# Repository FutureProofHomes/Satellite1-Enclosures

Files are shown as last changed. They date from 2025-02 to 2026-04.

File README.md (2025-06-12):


<!--
*** Readme based upon Best-README-Template.
-->

<!-- PROJECT SHIELDS -->
<!--
*** I'm using markdown "reference style" links for readability.
*** Reference links are enclosed in brackets [ ] instead of parentheses ( ).
*** See the bottom of this document for the declaration of the reference variables
*** for contributors-url, forks-url, etc. This is an optional, concise syntax you may use.
*** https://www.markdownguide.org/basic-syntax/#reference-style-links
-->
[][contributors-url]
[][forks-url]
[][stars-url]
[][issues-url]
[][license-url]
[][linkedin-url]

<!-- PROJECT LOGO -->
<br />
<div align="center">
  <a href="https://github.com/FutureProofHomes/Satellite1-Enclosures">
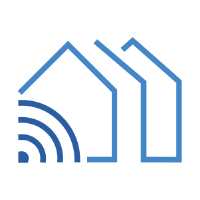
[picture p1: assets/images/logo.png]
    
  </a>

<h3 align="center">Satellite1 Voice Assistant Enclosures</h3>

  <p align="center">
    3D printable geometry and project files for enclosures relating to the Satellite1 AI-Powered Voice Assistant and its accessories.
    <br />
    <a href="https://docs.futureproofhomes.net"><strong>Explore the docs »</strong></a>
    <br />
    <br />
    <a href="https://www.youtube.com/@futureproofhomes">View Demos</a>
    ·
    <a href="https://github.com/FutureProofHomes/Satellite1-Enclosures/issues/new?labels=bug&template=bug-report---.md">Report Bug</a>
    ·
    <a href="https://github.com/FutureProofHomes/Satellite1-Enclosures/issues/new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">Request Feature</a>
  </p>
</div>

<!-- TABLE OF CONTENTS -->
<details>
  <summary>Table of Contents</summary>
  <ol>
    <li>
      <a href="#about-the-project">About The Project</a>
    </li>
    <li>
      <a href="#getting-started">Getting Started</a>
    </li>
    <li><a href="#contributing">Contributing</a></li>
    <li><a href="#license">License</a></li>
    <li><a href="#contact">Contact</a></li>
    <li><a href="#acknowledgments">Acknowledgments</a></li>
  </ol>
</details>

<!-- ABOUT THE PROJECT -->
## About the Project
The enclosures in this repo relate to the Satellite1 Voice Assistant

<div style="text-align: center;">
    <a href="https://docs.futureproofhomes.net/satellite1-squircle-enclosures">
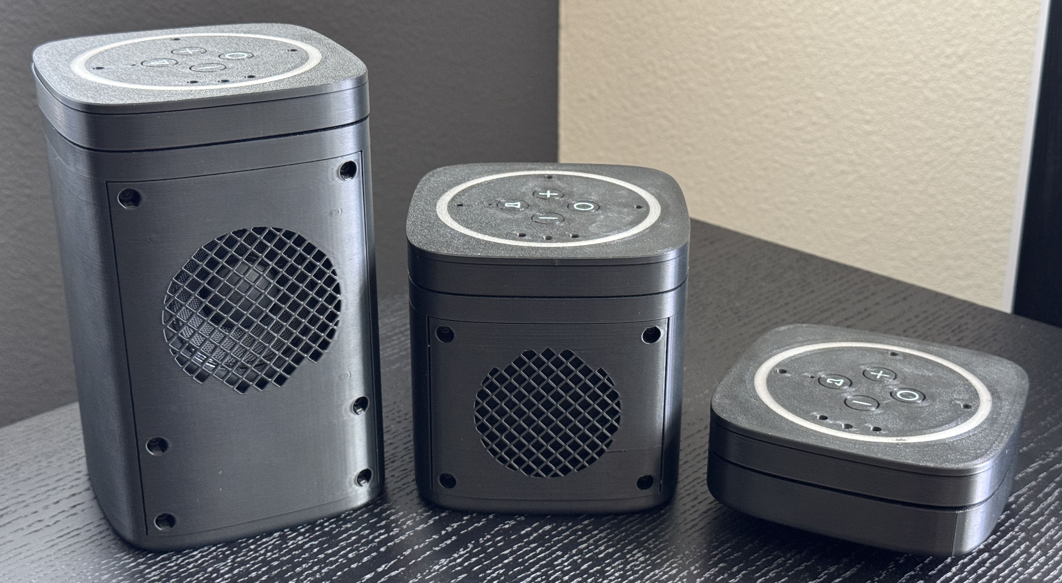
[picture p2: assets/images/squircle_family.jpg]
Sat1 Pose Tall
        
    </a>
</div>

<!-- GETTING STARTED -->
## Getting Started

Go to [Docs.FutureProofHomes.net/satellite1-squircle-enclosures](https://docs.futureproofhomes.net/satellite1-squircle-enclosures) and follow the instructions to print and assemble your enclosure.

<!-- CONTRIBUTING -->
## Contributing

Contributions are what make the open source community such an amazing place to learn, inspire, and create. Any contributions you make are **greatly appreciated**.

If you have a suggestion that would make this better, please fork the repo and create a pull request. You can also simply open an issue with the tag "enhancement".
Don't forget to give the project a star! Thanks again!

1. Fork the Project
3. Create your Feature Branch (`git checkout -b feature/AmazingFeature`)
4. Commit your Changes (`git commit -m 'Add some AmazingFeature'`)
5. Push to the Branch (`git push origin feature/AmazingFeature`)
6. Open a Pull Request

<p align="right">(<a href="#readme-top">back to top</a>)</p>

<!-- LICENSE -->
## License

Distributed under the CERN Open Hardware Licence Version 2 - Strongly Reciprocal Licesnse. See LICENSE.txt for more information.  See `LICENSE.txt` for more information.

<p align="right">(<a href="#readme-top">back to top</a>)</p>

<!-- CONTACT -->
## Contact

FutureProofHomes  - [Website](https://futureproofhomes.net/)

<p align="right">(<a href="#readme-top">back to top</a>)</p>

<!-- YouTube -->
## YouTube

Checkout out our growing YouTube Channel  - [YouTube.com/@FutureProofHomes](https://www.youtube.com/@futureproofhomes)

<p align="right">(<a href="#readme-top">back to top</a>)</p>

<!-- ACKNOWLEDGMENTS -->
## Acknowledgments

* @alextrical for the beautiful CAD work
* @j4ys0n for the early prototypes
* Your name here soon...

<p align="right">(<a href="#readme-top">back to top</a>)</p>

<!-- MARKDOWN LINKS & IMAGES -->
<!-- https://www.markdownguide.org/basic-syntax/#reference-style-links -->
[contributors-shield]: https://img.shields.io/github/contributors/FutureProofHomes/Satellite1-ESPHome.svg?style=for-the-badge
[contributors-url]: https://github.com/FutureProofHomes/Satellite1-Enclosures/graphs/contributors
[forks-shield]: https://img.shields.io/github/forks/FutureProofHomes/Satellite1-ESPHome.svg?style=for-the-badge
[forks-url]: https://github.com/FutureProofHomes/Satellite1-Enclosures/network/members
[stars-shield]: https://img.shields.io/github/stars/FutureProofHomes/Satellite1-ESPHome.svg?style=for-the-badge
[stars-url]: https://github.com/FutureProofHomes/Satellite1-Enclosures/stargazers
[issues-shield]: https://img.shields.io/github/issues/FutureProofHomes/Satellite1-ESPHome.svg?style=for-the-badge
[issues-url]: https://github.com/FutureProofHomes/Satellite1-Enclosures/issues
[license-shield]: https://img.shields.io/github/license/FutureProofHomes/Satellite1-ESPHome.svg?style=for-the-badge
[license-url]: https://github.com/FutureProofHomes/Satellite1-Enclosures/blob/master/LICENSE.txt
[linkedin-shield]: https://img.shields.io/badge/-LinkedIn-black.svg?style=for-the-badge&logo=linkedin&colorB=555
[linkedin-url]: https://linkedin.com/in/linkedin_username
[genaimockup]: assets/images/mockup.png
[combo_render]: assets/images/combo_render.png
[kicad.org]: https://img.shields.io/badge/KiCad-314CB0?style=for-the-badge&logo=kicad&logoColor=white
[kicad-url]: https://www.kicad.org/
[esphome.io]: https://img.shields.io/badge/-ESPHome-000000?style=for-the-badge&logo=esphome&logoColor=white
[esphome-url]: https://esphome.io/

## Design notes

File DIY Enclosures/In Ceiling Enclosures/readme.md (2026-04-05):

This is the minimalistic enclosure to place your Sat1.x DevKit into the ceiling<br>
<br>
it is designed to be powered through USB or with our PoE Shoe (est. availabilty end 2026)<br>
This enclosure isn't designed to host an speaker inside.<br>
<br>
You need following extra parts aside the DevKit itself:<br>
- <a href="https://aliexpress.com/item/1005010265420927.html">4x M3x12mm self tapping screws<br>
- <a href="https://aliexpress.com/item/1005010265420927.html">4x M3x4mm self tapping screws<br>
- <a href="https://aliexpress.com/item/1005009490995202.html">4x Downlight Spring Bracket<br>
<br>
For easy printing, use the provided Slicer Project files.<br>
the faceplate mesh is created with a height modifier inside the project.<br>
- use a height modifier from 0.00-2.00mm<br>
- set top and bottom layers to 0<br>
- set infill to 70%<br>
- set infill to tri-hexagon<br>
- set "only one wall on first layer"<br>
<br>
Be aware, your filament flow has to be dialed in.

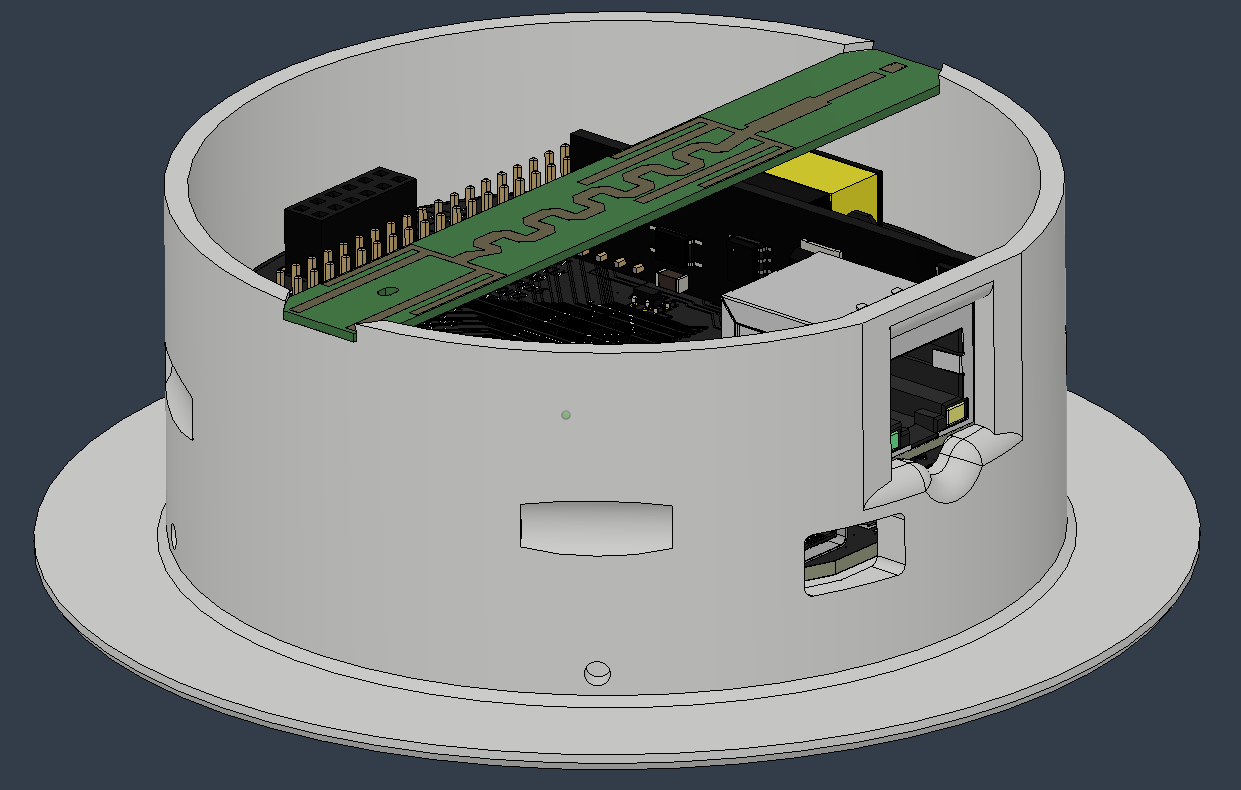
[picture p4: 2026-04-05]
DIY Enclosures/In Ceiling Enclosures/pictures/In Ceiling Mini.png

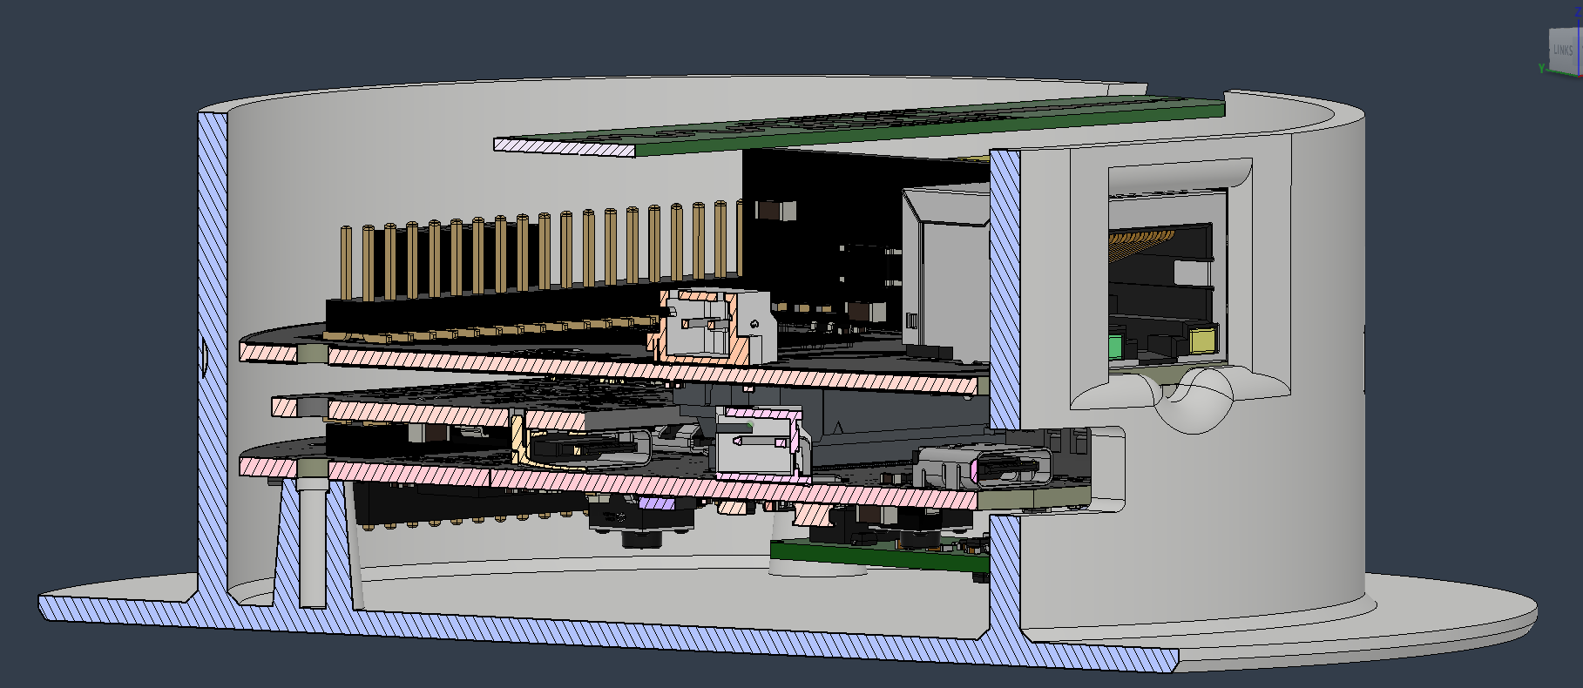
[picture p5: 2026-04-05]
DIY Enclosures/In Ceiling Enclosures/pictures/In Ceiling Mini cross cut view.png

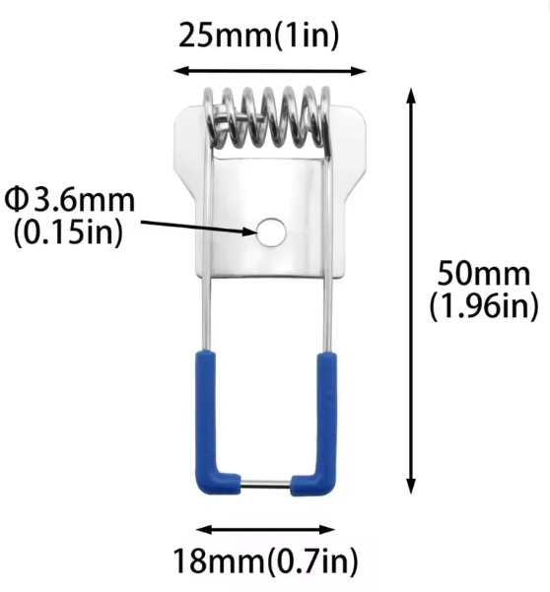
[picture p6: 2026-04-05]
DIY Enclosures/In Ceiling Enclosures/pictures/Spring brackets.png

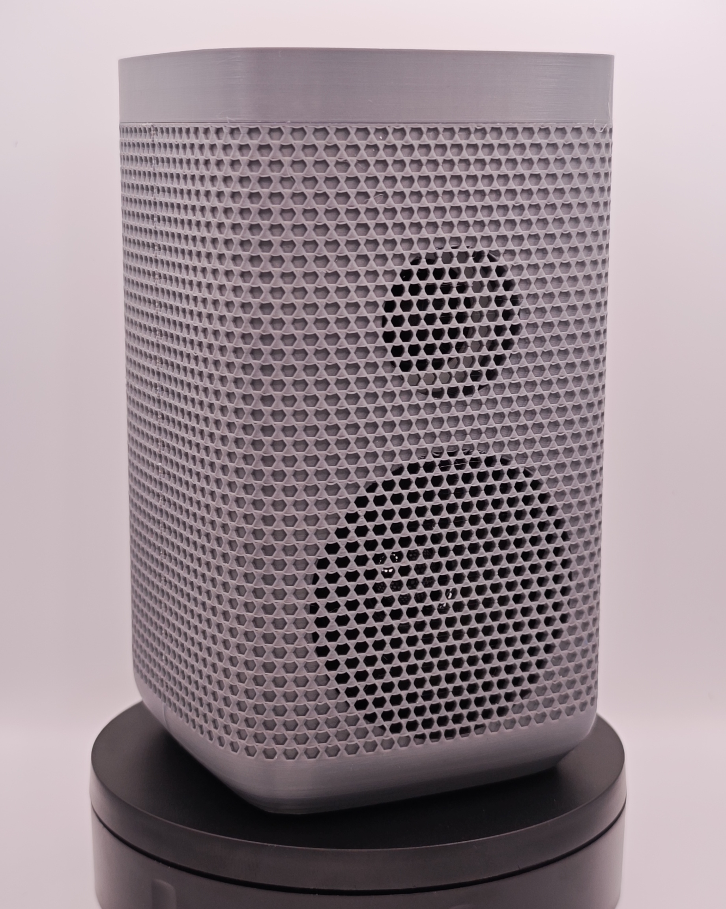
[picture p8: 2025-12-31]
assets/images/sat1_enclosure_kit.jpg

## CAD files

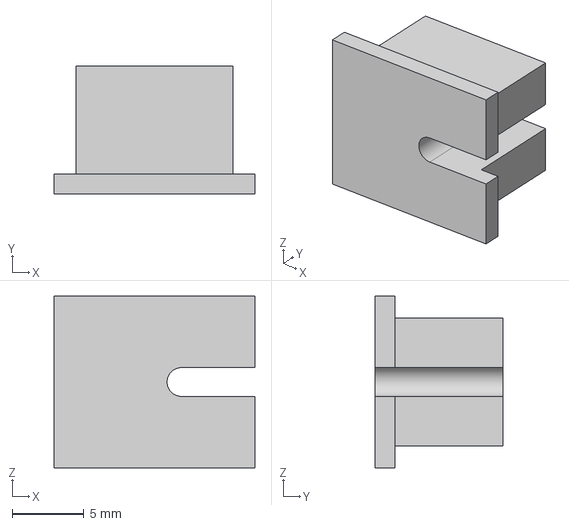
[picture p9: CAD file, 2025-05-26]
DIY Enclosures/Cylindrical Enclosures/Geometry Files/STEP/General Parts/2mm Wire Cover.step
14.0 x 8.90 x 11.9 mm

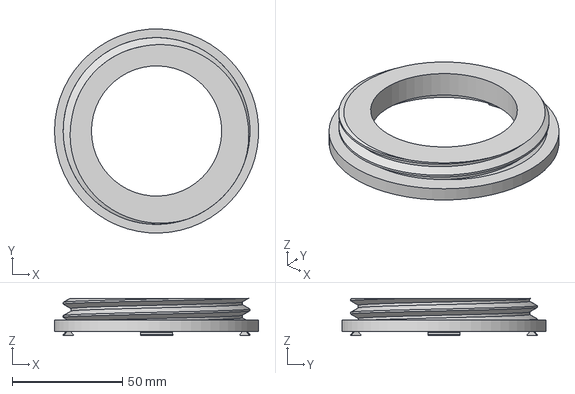
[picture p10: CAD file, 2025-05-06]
DIY Enclosures/Cylindrical Enclosures/Geometry Files/STEP/Speaker - Dayton Audio RS75-4/Speaker Adapter - RS75-4.step
92.4 x 92.5 x 16.9 mm

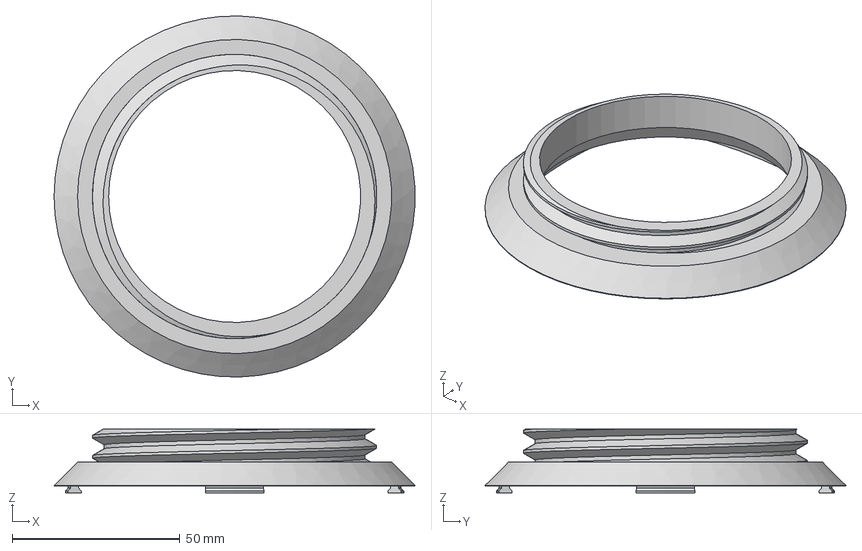
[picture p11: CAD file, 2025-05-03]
DIY Enclosures/Cylindrical Enclosures/Geometry Files/STEP/Speaker - GRS 3FR-4/Speaker Adapter - GRS 3FR-4.step
107.4 x 107.5 x 18.9 mm

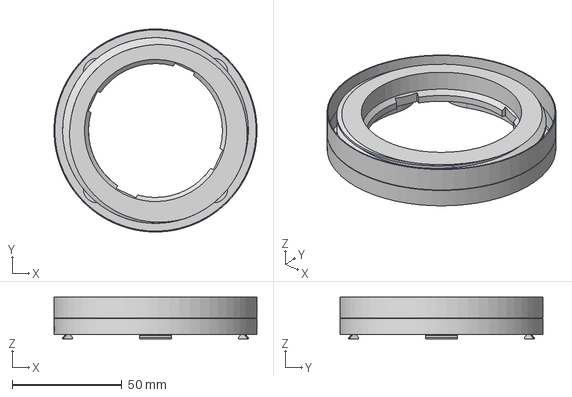
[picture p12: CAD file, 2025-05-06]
DIY Enclosures/Cylindrical Enclosures/Geometry Files/STEP/Speaker - TEBM46C - 20N/Speaker Adapter - TEBM46C-20N.step
92.5 x 92.5 x 18.9 mm

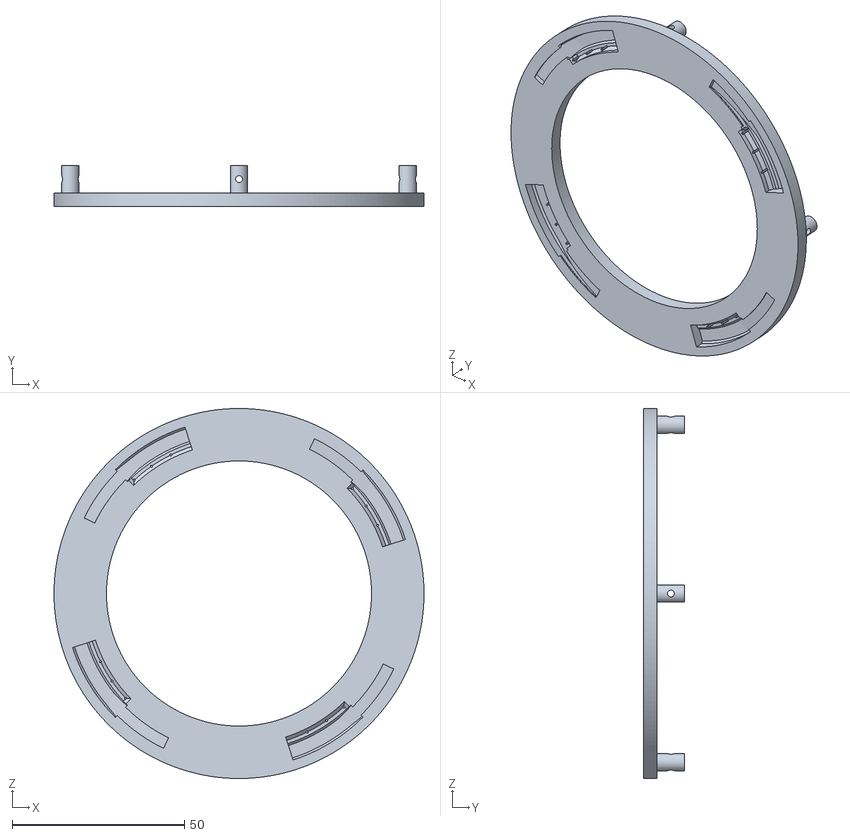
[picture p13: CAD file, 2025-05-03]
DIY Enclosures/Cylindrical Enclosures/Geometry Files/STL/Speaker - GRS 3FR-4/Stand Lock Ring - GRS-3FR-4.stl
107.5 x 12.0 x 107.5

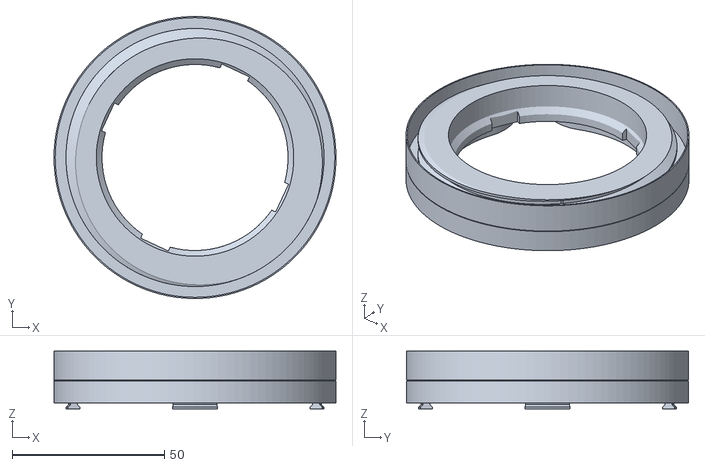
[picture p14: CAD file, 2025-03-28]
DIY Enclosures/Cylindrical Enclosures/Geometry Files/STL/Speaker - Tectonic TEBM46C-20N/Speaker Adapter - TEBM46C-20N.stl
92.5 x 92.5 x 19.0

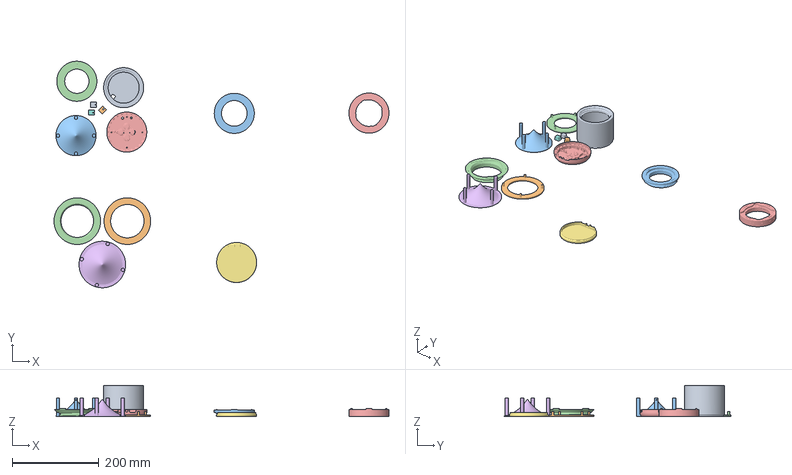
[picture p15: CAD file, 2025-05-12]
DIY Enclosures/Cylindrical Enclosures/OrcaSlicer - Sat1 Dev Kit Speaker Enclosure.3mf
772.9 x 522.8 x 72.1 mm
Speaker Chamber Threaded.stl
Stand Lock Ring - GRS-3FR-4.stl
Speaker Adapter - RS75-4.stl
Speaker Adapter - GRS-3FR-4.stl
Speaker Adapter - TEBM46C-20N.stl
GRS-3FR-4 Speaker Stand
(Optional) Dev Kit UFO Base for No Speaker.stl
1.5mm Wire Cover.stl
1mm Wire Cover.stl
2mm Wire Cover.stl
Speaker Stand.stl
Lock Ring.stl
Dev Kit UFO Enclosure.stl

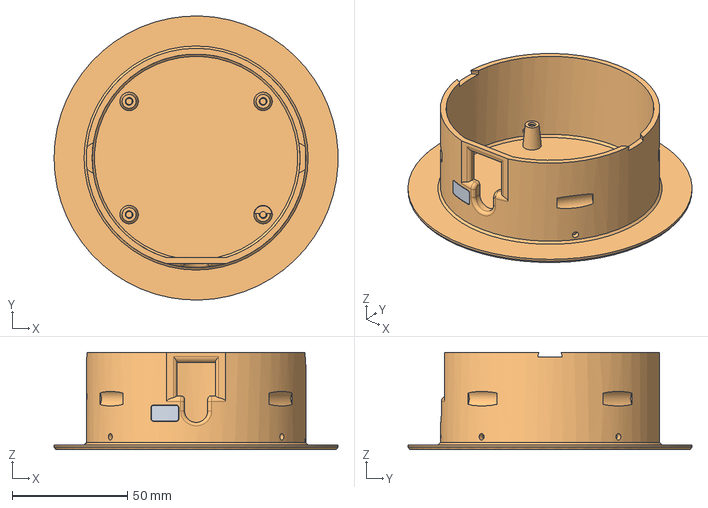
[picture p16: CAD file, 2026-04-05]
DIY Enclosures/In Ceiling Enclosures/geometry/STEP/In Ceiling Mini Enclosure.step
122.9 x 123.0 x 42.0 mm

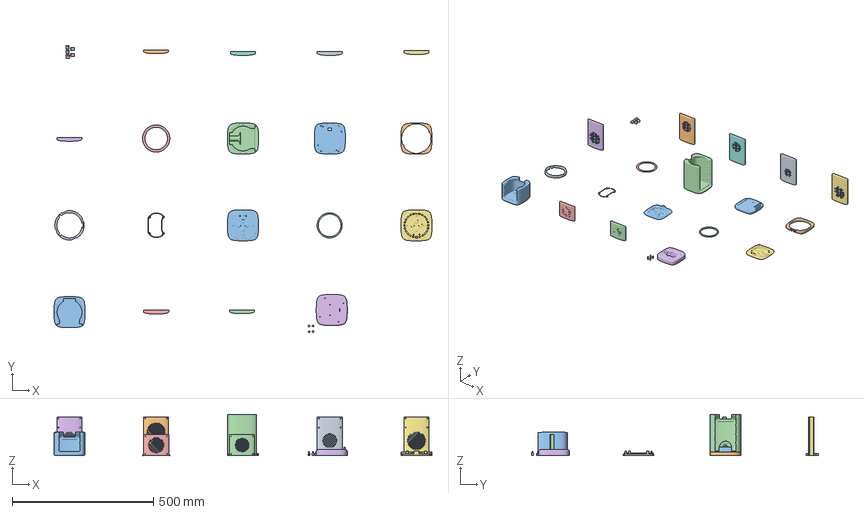
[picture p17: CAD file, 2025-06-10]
DIY Enclosures/Squircle Enclosures/Bambu Studio - Squircle Enclosure.3mf
1337.6 x 1016.5 x 145.8 mm
Speaker Plate Dayton Audio RS75-4 3in.stl
Speaker Plate GRS 3FR3 and Visaton FRS8-4 3.3in.stl
Wire Cover 1.5mm.stl
PCB Spacer.stl
Wire Cover 1mm.stl
Wire Cover 3mm.stl
Top Plate.stl
Top Plate Snap-In Diffuser Ring.stl
Mid-Plate Threads.stl
Lock Ring.stl
Mid-Plate.stl
25-Watt Speaker Chamber.stl
25-Watt Speaker Chamber Anti-Slip Ring.stl
Speaker Plate Dayton Audio PC83-4 3in.stl
Speaker Plate FaitalPRO 3FE25 3in.stl
Speaker Plate Tectonic TEBM46C20N-4 v5.stl
Wire Cover 2.5.stl
Wire Cover 2mm.stl
15-Watt Speaker Chamber.stl
15-Watt Speaker Plate Triple Speaker.stl
15-Watt Speaker Plate Tectonic TEBM46C20N-4.stl
3-Watt Speaker Chamber.stl
3-Watt Speaker Chamber Legs x 4.stl x 4
Top Plate MM Buttons

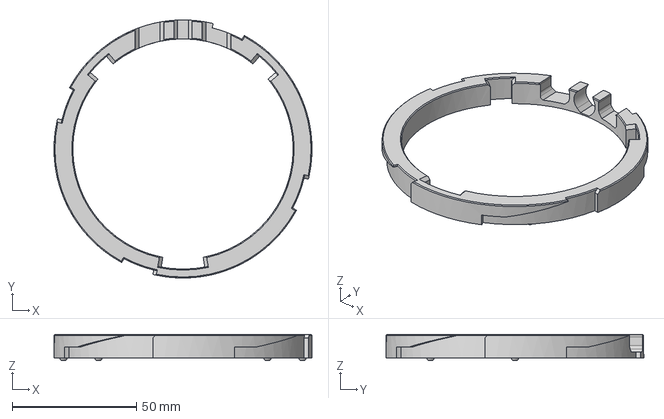
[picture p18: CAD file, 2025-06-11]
DIY Enclosures/Squircle Enclosures/Geometry Files/STEP/Mid-Plate/Mid-Plate Threads.step
104.0 x 104.0 x 10.6 mm

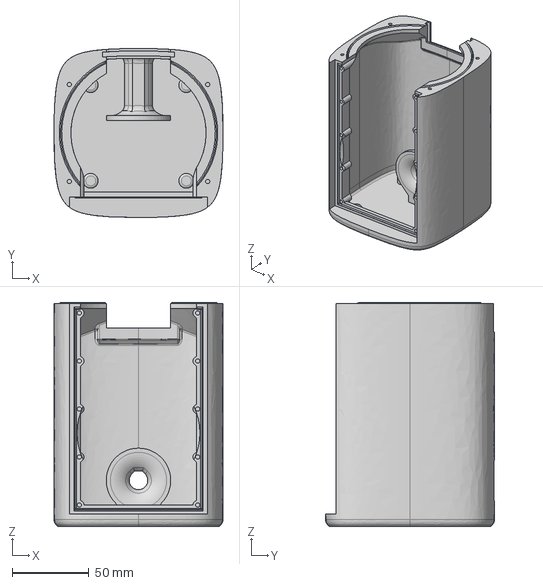
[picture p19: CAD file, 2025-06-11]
DIY Enclosures/Squircle Enclosures/Geometry Files/STEP/Speaker Chamber/25-Watt Speaker Chamber.step
110.0 x 110.0 x 145.8 mm

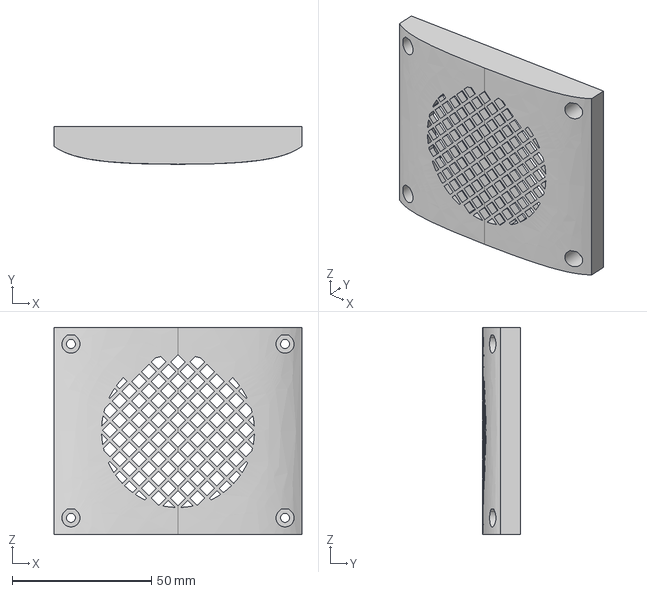
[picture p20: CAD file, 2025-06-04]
DIY Enclosures/Squircle Enclosures/Geometry Files/STEP/Speaker Plates/15-Watt Speaker Plate Tectonic TEBM46C20N-4.step
89.2 x 13.5 x 74.5 mm

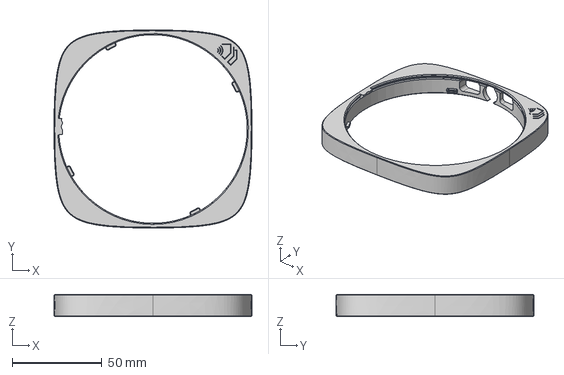
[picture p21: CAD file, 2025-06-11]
DIY Enclosures/Squircle Enclosures/Geometry Files/STEP/Squircle Top/Lock Ring.step
110.0 x 110.0 x 12.3 mm

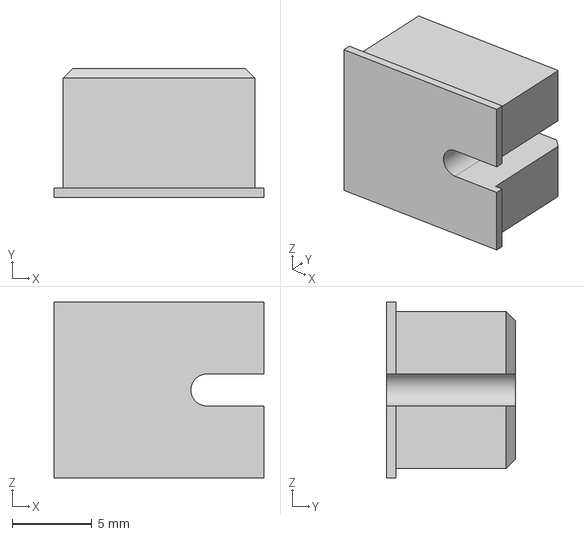
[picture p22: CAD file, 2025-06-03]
DIY Enclosures/Squircle Enclosures/Geometry Files/STEP/Wire Covers/Wire Cover 2mm.step
13.2 x 8.10 x 11.0 mm

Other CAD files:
DIY Enclosures/In Ceiling Enclosures/In Ceiling Mini Enclosure (Bambu Studio Project).3mf
OEM Enclosures/Satellite1 Smart Speaker Enclosure Kit/Geometry Files/STEP/Bonus/Minimalistic Chamber (optional 3525 speaker).step
OEM Enclosures/Satellite1 Smart Speaker Enclosure Kit/Geometry Files/STEP/LED Diffuser.step
OEM Enclosures/Satellite1 Smart Speaker Enclosure Kit/Geometry Files/STEP/MultiMaterial/Top Plate (MultiMaterial including diffuser).step
DIY Enclosures/Cylindrical Enclosures/Bambu Studio - Sat1 Dev Kit Speaker Enclosure.3mf
DIY Enclosures/Cylindrical Enclosures/Geometry Files/STEP/General Parts/(Optional) Dev Kit UFO Base for No Speaker.step
DIY Enclosures/Cylindrical Enclosures/Geometry Files/STEP/General Parts/1.5mm Wire Cover.step
DIY Enclosures/Cylindrical Enclosures/Geometry Files/STEP/General Parts/1mm Wire Cover.step
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

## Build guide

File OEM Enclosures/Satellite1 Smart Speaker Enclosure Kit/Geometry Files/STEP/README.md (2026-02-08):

This files are meant for single color / single material print<br>
You'll find multimaterial replacements within the multimaterial folder<br>
Files in the bonus folder aren't needed for building the Mesh Enclosure<br>

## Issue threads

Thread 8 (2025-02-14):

Speaker for enclosure

Buzz58, 2025-02-14:
Will there be a new design? The speaker you have chosen is unavailable.

Thanks
Rich

that1guy, 2025-02-15:
Yes!  We're shopping for "good", "better" and "best" speakers we're going to recommend and design enclosures for.

If you have a special speaker you'd like to accommodate the geometry is open-source and can be modified and printed at home.

Buzz58, 2025-02-21:
Thank You, good news.

Richard Marte

Pres.

Mart-tex Athletics, Inc.

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

kubanm3, 2025-04-11:
Hi, will there be options for in-ceiling ones? Plus being able to power it directly from 230v mains would be appreciated.

that1guy, 2025-04-20:
Hello all,

We now support 3 speakers:

1. GRS 3RF-4 4" driver.  IN STOCK! (requires a [slightly custom stand](https://github.com/FutureProofHomes/Satellite1-Enclosures/pull/21) since it's a larger speaker)
2. Dayton Audio RS75-4 3" driver.  CURRENTLY OUT OF STOCK AT THIS MOMENT.
3. Tectonic TEBM46C20N-4B BMR 3" driver.  CURRENTLY OUT OF STOCK AT THIS MOMENT.

We are working on adding a choice of speakers to the actual dev kit that will ship in the mail.  Customers will get to choose their speaker or bring their own if they still prefer.  Stay tuned.

ssurovich, 2025-06-12:
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

Im confused as well - even the link to the speaker in the docs shows it as a 3" speaker, not a 4"?

Closed 2025-04-20.

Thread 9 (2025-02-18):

UFO and LD2450 needs more space

CyberGWJ, 2025-02-18:
When uninstalling the UFO with the LD2450 there is a bulge on the top.  Looking inside after removing the Sat 1 there in an impression of the top chip of the LD2450.  See pictures.

Bulge

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

Impression

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

CyberGWJ, 2025-02-18:
I do not know if it is a space issue with the UFO or the heat from the LD2450.

that1guy, 2025-02-18:
Interesting.  Can you shared exactly which version of the LD2450 you're running?  Give us link to the product?

In my transparent 3d print I can see my LD2450 is not causing this issue.  Perhaps this is heat related?

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

CyberGWJ, 2025-02-18:
Here is the link to the one I ordered off Amazon.

https://www.amazon.com/gp/product/B0CQ2P4RVP/ref=ppx_yo_dt_b_search_asin_title?ie=UTF8&th=1

Will reprint this afternoon.

CyberGWJ, 2025-02-18:
@that1guy Printed the UFO in transparent PLA and I could not tell it how the LD2450 was sitting.  So, I cut the side out of the UFO.  It seems that the LD2450 is a little tight at the top.  There is a gap which is about the height of the chip on top of the board.

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

that1guy, 2025-04-28:
@alextrical @CyberGWJ I don't think we should do this as it may have negative consequences for all the other sensors on the HAT.  Let me explain:

If we make the UFO print taller to give more room it will causes:
1. The mic pipes to be even longer, impacting the mics ability to hear the room
2. The temp/humidity and lux sensors to get even more inaccurate readings of the room

I think the better solution is to simply recommend customers print the current design with PETG (which the documentation already does).  If you agree I think we should close this ticket.

Closed 2025-05-07.

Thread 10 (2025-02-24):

repurpose enclosures?

a011528, 2025-02-24:
I have been closely following your progress for some time now and, although I don't yet have the Dev Kit, I am on your waitlist and very excited about your plans. They just make sense!

My primary goal is to replace Alexa throughout my house, but this leaves me with a bit of a dilemma. I have all these unused devices that would effectively become junk. Would the Satellite Hat board fit into any existing Alexa enclosure? Or do you have plans to make them compatible in some way? Repurposing the enclosure and built-in speaker would not only save some costs but would also be beneficial for the environment, many of these devices are quite aesthetically pleasing, so it would be a shame to waste them. I recall seeing a hint towards this in one of your videos or pictures, but I might be mistaken.

On another note, I recognize this might not be the appropriate place to ask, but I was wondering if you have road map to introduce a screen with a camera at some point? And if so, would you support a VOD feature similar to drop-in or Meta's Portal WhatsApp?

Sangoku, 2025-03-02:
I would second that. I have 6 alexas and the sound of them is not half bad. Would love to be able to repurpose them.

that1guy, 2025-04-20:
Hello all,

I do get the ask here and understand why it would be enticing.  The [Onju Voice project](https://github.com/justLV/onju-voice) seems more likely to be able to help here.  We have decided not the build a product that fits inside Alexa for a couple reasons:

1. Requires customers to purchase a product, tear it down and build it back up, which will have issue scaling.
2. We want to avoid any legal confrontations with these companies.
3. We want to build a single PCB that works on the desk, with many speakers, and in the ceiling.  Another requirements constraint to fit inside Alexa shell is very hard.

In the near future we will have all the components necessary in a single dev kit box, including the enclosure.

Cheers all!  Thank you so much for sharing your ideas though.

Closed 2025-04-20.

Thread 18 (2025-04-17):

Trouble Printing Threaded Speaker Adapters

hdprice, 2025-04-17:
Love the project, hate the stupid screw fit for the lock ring. OMG. Just the worst! Printed the parts four times, and none of them fit. PLEASE redesign this connection. It just doesn't work as it is. And yes, my filament is dry and, yes, my printer is calibrated.

that1guy, 2025-04-17:
@hdprice Can you share some images of your resulting print.  Sometimes those visual clues can help determine the root cause.  Also please let us know what printer you're using.

Thanks!

that1guy, 2025-04-20:
Anybody else having issues here?  Please share photos of your challenges and printer models/settings.  TY!

that1guy, 2025-05-07:
Closing this issue as many folks have successfully printed.  Also, please check the updated files!

Closed 2025-05-07.

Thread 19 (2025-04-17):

Bambu Studio Beta Warning

guillaumemolter, 2025-04-17:
When opening the file with the latest version of Bambu Studio, I am seeing the following two error messages:

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

You might want to use a stable version to export files moving forward to avoid this.

that1guy, 2025-04-20:
Solved with latest project files. :)

https://github.com/FutureProofHomes/Satellite1-Enclosures/tree/main/Satellite1%20Dev%20Kit%20Speaker%20Enclosure/Project%20Files

Closed 2025-04-20.

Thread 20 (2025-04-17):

Invalid caracter error in Bambu Studio

guillaumemolter, 2025-04-17:
I'm seeing the following error when opening the latest 3mf files:

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

I think as a result , plate 2 doesn't have a label on it:

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

Using:

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

that1guy, 2025-04-20:
Solved with latest project files.  :)

https://github.com/FutureProofHomes/Satellite1-Enclosures/tree/main/Satellite1%20Dev%20Kit%20Speaker%20Enclosure/Project%20Files

Closed 2025-04-20.

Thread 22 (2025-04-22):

STL request

RIMSKO, 2025-04-22:
Can we get a modified version of the Dev Kit UFO Base for No Speaker that fits the Dev Kit with POE Hat.

jayceegee87, 2025-04-24:
It would also be helpful to have a version of the UFO hat for non-multicolor printers. Something that allows you to print the transparent piece separately from the rest of the UFO hat.

that1guy, 2025-05-07:
Hey gents, the PoE SHOE board isn't finalized yet so we can't release enclosures yet.  I'm going to close this ticket for now, but as the SHOE board get's released we will get this done!

Closed 2025-05-07.

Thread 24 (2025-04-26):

Current STEP files

withanhdammit, 2025-04-26:
Do you have current STEP files for the printable parts?  Even better if you have Fusion 360 project files.  The ones in the repo do not look current ones.

that1guy, 2025-05-07:
@withanhdammit all STL files have been uploaded.

We can't share fusion due to commercial licensing challenges and being the cost of Fusion licenses.

Closed 2025-05-07.

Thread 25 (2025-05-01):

UFO stl file does not convert correctly in Fusion 360

HA5412, 2025-05-01:
When importing the UFO enclosure into Fusion 360 it does not convert correctly. It ends up with a bladder like shape. See attached screenshots

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

HA5412, 2025-05-07:
1. The STL file will import fine. It is in the conversion to a component that the problem arises. It is because of the second body for the translucent area. See pictures above.

2. The step files open up fine. Now I can make adjustment to it.

Thanks

alextrical, 2025-06-11:
Hi

We are closing this ticket as we believe this issue is resolved. The Step files have been proided to allow editing gemotery.

Please feel free to repoen this issue if you believe this is not the case

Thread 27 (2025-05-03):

Main Housing thread misalignment with body

gumpdy, 2025-05-03:
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

Model doens't seem to be drawn on the primary planes. Everything is modeled concentrically with the housing except for the threads which were modeled concentric with the model origin.

that1guy, 2025-05-07:
@gumpdy can you check the new files that we've uploaded to see if this issue persists?

cc @alextrical

gumpdy, 2025-05-07:
Ill grab them tomorrow and report back.

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

RMatthewCole, 2025-05-09:
Which files have been updated? I downloaded the Bambu Studio file and the center speaker offset there was still incorrect. I'll run another quick print of the individual STLs if those have been updated to verify.

RMatthewCole, 2025-05-10:
I pulled down the speaker enclosure STL file last night and printed it. It's still off center as of 5/8. If I should be pulling the changed file from someplace else let me know and I'll run a test print.

gumpdy, 2025-05-10:
I checked RS75-4 adapter STEP and the main speaker tube and they are still misaligned 🤦 @that1guy I'm not sure why this requires a peer review

alextrical, 2025-05-12:
@gumpdy Yes the issue is caused by the centre of the PCB being off by 1mm.
I will get the ammended file uploaded in the next 60 minutes.

Closed 2025-05-12.

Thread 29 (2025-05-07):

how do you print tyese things with all the overhangs

sdetweil, 2025-05-07:
i am printing on an ender 3v2, slicing w cura

tried pla and petg   both in tye middle of the head temp range, the threads are a mess with all the overhanging parts

the top is a jumble of threads all over the place dont see how the buttons would work,
the body threads are unusable

i added use support on the speaker adapter , and i have a  near solid block, cant see the threads

if you print it w the tabs down, then its mostly in thin air above that, if you print tabs up then you have the overhang around the threads

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

funat120mph, 2025-05-08:
@sdetweil For the top/button piece, print with the buttons flat on the print bed.

I use no supports and pause to start the color change at my Layer 9 → that’s at Z = 1.38 mm and revert the color after Layer 65 → that’s at Z = 8.94 mm for the clear ring (I Ion't have multifilament yet...)

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

For the other parts, which are you printing? Can you post the stl files or the GitHub repo?

I have printed all of these many times...I am by far a printing expert and I have been successful...most of the time.

sdetweil, 2025-05-08:
i am using this repo, printing from the general parts stl

and the dayton speaker adapter

attached orientation?  dont see attachment

funat120mph, 2025-05-08:
Here’s the orientation on the build plate.

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

I will print another chamber this morning to make sure I didn’t use supports.

sdetweil, 2025-05-08:
ah, part orientation on build plate

the stl should be saved that way!

i printed the top outside face down, and its better
may go back to pla, dont like the shiny petg

trying a grs speaker adapter  now, threads up

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

just fyi

the new update 2 days ago changed the stl files, but says sync

we could use some change log to tell us if we need to get the new files , and why.

funat120mph, 2025-05-08:
Well, I ended up with some spaghetti on my reprint this afternoon and some poor threads.  I remember now that I combined the speaker chamber and the GRS-3FR adapter.

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

funat120mph, 2025-05-08:
[GRS-3FR Speaker Chamber.txt](https://github.com/user-attachments/files/20111068/GRS-3FR.Speaker.Chamber.txt)

Change the extension to .stl

This is the one I created using Tinkercad. I'm not a designer!!!

cowboysdude, 2025-05-11:
Hey!! I printed mine on an Ender3 and enabled supports.   The prints came out much nicer but not fun getting some of the supports out LOL.

sdetweil, 2025-05-11:
@cowboysdude  you following me around???  lol.. were you using PLA? or PETG?

just trying to get acceptable other people looking at quality..

cowboysdude, 2025-05-11:
I am... I'm stalking you LOL    My prints got MUCH better after I added supports to them...because I was getting the same kind of threading you were getting.

sdetweil, 2025-05-11:
did you see my speaker ring with supports??

https://private-user-images.githubusercontent.com/1498142/441462128-b1dbf8bd-1848-4c3b-974e-4d3255e54ca2.jpeg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

hardly usable , lol...

yes, multi-color has got to be a challenge..

cowboysdude, 2025-05-11:
There is the problem....  I started out with issues because I think they were using a different printer then I was to print the parts... I was using and Ender 3 not sure what they were using but, and I wish I didn't lose my stl files, had to redo my computer yesterday and didn't save them, because mine printed soooooo much better...after I added supports to mine.

What brand printer are you using?

sdetweil, 2025-05-11:
I am using and Ender 3 V2, prints all kinds of things great. I use Cura for the slicer

overhangs are always a problem ..
I've made all kinds of things on thingaverse and printed without trouble (except when they don't touch the bed!!)

sdetweil, 2025-05-11:
STL is supposed to be printer agnostic.. the slicer converts to printer specific commands

cowboysdude, 2025-05-11:
Very strange..... they should be printing pretty well on that printer... OHhhhhhhhhhhhh I think I found the prints still on the SD card in my printer... What is the name of that stl... I may still have it.

sdetweil, 2025-05-11:
Speaker Adapter - RS75-4.stl

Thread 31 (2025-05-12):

Speaker Auswahl für Europa

Trunks1982, 2025-05-12:
Hallo könnte villeicht auch ein Lautsprecherring angefertigt werden für Lautsprecher die in Europa / Deutschland gut verfügbar sind?
Die 3-4 Lautsprecher die sie Empfehlen sind in Deutschland sehr schwer zubekommen.

Gruss Christoph

Closed 2025-06-10.

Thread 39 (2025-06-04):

squircles mid plate ring debris in outside channels

sdetweil, 2025-06-04:
on the mid plate ring, which has the  angular channels on the outside of threads shown here 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

to allow top to rotate, when printed w PETG,  the angular slots were filled w debris. wasn't obvious til one came out.

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

should probably mention it in the assembly doc

alextrical, 2025-06-11:
Hi

Im not sure i fully understand the issue. Is it the "Nubs" on the Threads not fully seating into the Mid Plate?

alextrical, 2025-06-27:
The lock ring has been ammended to reduce the complexity for consumer 3d printing. Please try with the new file. If the issues persists please feel free to re-open this ticket

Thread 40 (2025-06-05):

hard to install diffuser ring

sdetweil, 2025-06-05:
I printed the top outside down using PETG, and diffuser using clear PLA, now can't get diffuser into top.

any advice?

that1guy, 2025-06-10:
@sdetweil your print looks very rough and severely under-extruded.  Have you cleaned the nozzle, dried filament and confirmed temperature is correct on the hot end?

Apologies - I'm not trying to offend your 3D printer either! :) But I'm pretty certain the print quality is the issue.

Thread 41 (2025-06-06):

Speakers for Europe / UK

a011528, 2025-06-06:
Id like a List of speakers available in EU to fit the Cylindrical and "Squircle" none of the ones listed on the main site are available in Europe via Amazon and soundimport are out of stock

Do you have a list of Speakers that would fit, especially since i have already printed the the enclosures ?

that1guy, 2025-06-10:
@a011528 the list of speakers are in the documentation and many are available.

- [Squircle Enclosure](https://docs.futureproofhomes.net/satellite1-squircle-enclosures/#choose-a-speaker-and-enclosure-size)
- [Cylindrical Enclosure](https://docs.futureproofhomes.net/satellite1-dev-kit-enclosure/#cylindrical-dev-kit-enclosure)

Please close this ticket if this answers your questions.  Thank you!

a011528, 2025-06-10:
@that1guy none of the speakers are available in EU unless you go through specialist Imports stores, all your links lead to US amazon and not DE, UK, etc

a011528, 2025-06-11:
@that1guy Scenario Overview:

Your customers (the community) are expected to print the enclosures themselves using a 3D printer or by outsourcing the task to a friend or an online service—as I did. That part works well.

However, the challenge arises with the speakers. Unless these are readily available in each region at a reasonable price, customers are forced to deal with additional costs such as import duties and taxes, which can significantly increase the overall expense.

What’s Needed:

To make the solution more viable globally, we need:

A list of alternative speaker models that are compatible with the enclosures and available in different regions.
Optional: Adapter plates or mounting solutions that allow those alternative speakers to fit properly into the existing enclosure design.
Without these, the total cost may become prohibitive, undermining the accessibility and appeal of the solution.

alextrical, 2025-06-11:
hi @a011528

We are working on getting speakers added to out supply chain, so this should be less of an issue, but in the mean time if you could recommend a suitable speaker, that is 3" or less, available in your region with a datasheet, we can look at adding a speaker plate to support it.

As you have noted not all speakers are available in every region, and the speakers we have selected are just the ones we can get our hands on, The front plates concept was created to be modified by us and the community to accept any desired speakers.

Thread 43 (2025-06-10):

Screwing

Trunks1982, 2025-06-10:
Can you not use screw inlays on the screw connection so that it can be screwed securely?

alextrical, 2025-06-11:
Hi, Please can you clarify your question or provide an example of the issue that you are experiencing.

Im not sure what you mean by a screw inlay

Trunks1982, 2025-06-11:
I mean something like that instead of just screwing the screws into the plastic. It shouldn't be a big change.

https://amzn.eu/d/6g4JPmG

Trunks1982, 2025-06-28:
That last one was exactly what I was thinking, because apparently some people were having problems in Discord. It was just a suggestion.

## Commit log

2025-02-04 Initial Commit with Geometry & Project Files
    [1.5mm Wire Cover.stl, 1mm Wire Cover.stl, 2mm Wire Cover.stl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]
2025-02-05 Updating naming conventions and removing metadata files
    [R2024.12.06 Sat1 Dev Kit TEBM46C20N-4B Speaker Enclosure.3mf, TEBM46C20N-4B Speaker Chamber.stl]
2025-02-05 Updating folder naming conventions
    [1.5mm Wire Cover.stl, 1mm Wire Cover.stl, 2mm Wire Cover.stl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]
2025-02-10 Adding a bottom cap/base the user can optionally print
    - If you do not have a speaker you can use this base to cap off the UFO enclosure.
    [(Optional) Dev Kit UFO Base for No Speaker.stl]
2025-03-27 Added Step files for FPH PCB's Added Step files for threaded enclosure Added Collet for new speaker type
    [(Optional) Dev Kit UFO Base for No Speaker.stl, 1.5mm Wire Cover.stl, 1mm Wire Cover.stl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]
2025-03-27 correcting file name typos
    [Speaker Adapter - RS75-4.step, Speaker Adapter - RS75-4.stl, Speaker Adapter - TEBM46C-20N.step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]
2025-03-28 Corrected clerance for TEBM46C-20N terminals
    [Speaker Adapter - TEBM46C-20N.step, Speaker Adapter - TEBM46C-20N.stl]
2025-04-09 Adding OrcaSlicer proj. file back with new threaded speaker enclosure and adapters.
    [Sat1 Dev Kit Speaker Enclosure.3mf]
2025-04-15 Relocated JST XH port Simplified geometry for Hat + Core
    [Speaker Chamber Threaded.step, Speaker Chamber Threaded.stl]
2025-04-15 Added solid wire cover
    [1.5mm Wire Cover.stl, 1mm Wire Cover.stl, 2mm Wire Cover.step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]
2025-04-15 updating 3mf with latest designs and simplifying folder structure
    [(Optional) Dev Kit UFO Base for No Speaker.stl, 1.5mm Wire Cover.stl, 1mm Wire Cover.stl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]
2025-04-15 remove old 3mf
    [Sat1 Dev Kit Speaker Enclosure.3mf]
2025-04-20 Adding support for GRS 3FR-4 Speaker. Migrating to filament locking stand. Updating project files and folder structures.
    [(Optional) Dev Kit UFO Base for No Speaker.stl, 1.5mm Wire Cover.stl, 1mm Wire Cover.stl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]
2025-04-25 ensuring project files use latest speaker chamber
    [Bambu Studio - Sat1 Dev Kit Speaker Enclosure.3mf, OrcaSlicer - Sat1 Dev Kit Speaker Enclosure.3mf]
2025-05-01 Synced STL and SteP files for Speakers
    Also update Bambu and Orca Slicer project files
    [Bambu Studio - Sat1 Dev Kit Speaker Enclosure.3mf, OrcaSlicer - Sat1 Dev Kit Speaker Enclosure.3mf, Speaker Adapter - GRS 3FR-4.step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]
2025-05-02 Reorganized directory and files.
    [2mm Wire Cover.step, Sat1 Dev Kit Speaker Enclosure.3mf, Speaker Chamber Threaded.step]
2025-05-06 Sync STEP and STL Files Update the Orca and Bambu Projects to make sure all files are in sync
    [(Optional) Dev Kit UFO Base for No Speaker.step, (Optional) Dev Kit UFO Base for No Speaker.stl, 1.5mm Wire Cover.step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]
2025-05-12 Repaired 1mm offset thread on speaker chamber
    [Speaker Chamber Threaded.step, Speaker Chamber Threaded.stl]
2025-05-12 Updating Orca & Bambu project files to use latest speaker chamber
    [Bambu Studio - Sat1 Dev Kit Speaker Enclosure.3mf, OrcaSlicer - Sat1 Dev Kit Speaker Enclosure.3mf]
2025-05-26 Rename folders and release Squircle enclosure
    [(Optional) Dev Kit UFO Base for No Speaker.step, (Optional) Dev Kit UFO Base for No Speaker.stl, 1.5mm Wire Cover.step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]
2025-05-27 Adding Squircle project files and updated folder structure
    [(Optional) Dev Kit UFO Base for No Speaker.step, (Optional) Dev Kit UFO Base for No Speaker.stl, 1.5mm Wire Cover.step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]
2025-05-27 adding speaker chamber plugs
    [1.5mm Wire Cover.step, 1.5mm Wire Cover.stl, 1mm Wire Cover.step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]
2025-05-29 added additional Wire Covers
    [2.5mm Wire Cover.step, 2.5mm Wire Cover.stl, 3mm Wire Cover.step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]
2025-06-02 adding new mid-plate that gives room for larger screw heads
    [Bambu Studio - Squircle Enclosure.3mf, Mid-Plate.step, Mid-Plate.stl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]
2025-06-03 Corrected Wire cover with tight fit version
    [1.5mm Wire Cover.step, 1.5mm Wire Cover.stl, 1mm Wire Cover.step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]
2025-06-04 Updated Enclosure Design and Folder renaming
    [15-Watt Speaker Chamber.step, 15-Watt Speaker Chamber.stl, 15-Watt Speaker Plate Tectonic TEBM46C20N-4.step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]
2025-06-10 Amended Project files to use latest STL Files
    [Bambu Studio - Squircle Enclosure.3mf, OrcaSlicer - Squircle Enclosure.3mf]
2025-06-11 Replace main with Enclosure-Update contents
    [25-Watt Speaker Chamber.step, 25-Watt Speaker Chamber.stl, Bambu Studio - Squircle Enclosure.3mf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]
2025-06-11 Updated Project files to reflect STL changes
    [Bambu Studio - Squircle Enclosure.3mf, OrcaSlicer - Squircle Enclosure.3mf]
2025-12-31 reorganized to new folder structure, added new Satellite1 Smart Speaker OEM enclosure
    [(Optional) Dev Kit UFO Base for No Speaker.step, (Optional) Dev Kit UFO Base for No Speaker.stl, 1.5mm Wire Cover.step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]
2025-12-31 corrected typo
    [M - Screwing guide.3mf, M - Screwing guide.step, M - Top Plate.3mf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]
2026-02-08 updated folder structure and filenaming
    [LED Diffuser.step, LED Diffuser.stl, Minimalistic Chamber (optional 3525 speaker).step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]
2026-04-05 added Sat1.1 Mesh Squricle Large and In Ceiling Mini enclosures
    [In Ceiling Mini Enclosure (Bambu Studio Project).3mf, In Ceiling Mini Enclosure (Orca Slicer Project).3mf, In Ceiling Mini Enclosure.3mf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]
2026-07-22 removed gap at bottom shell
    [Sat1.x large - Chamber back - Wifi pocket + Bass port.stl]

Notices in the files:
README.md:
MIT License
